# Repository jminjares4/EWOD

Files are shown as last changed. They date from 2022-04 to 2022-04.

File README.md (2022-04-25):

# **EWOD** :zap:

## **Description**
This repository hold the hardware designed files for EWOD Senior project. The hardware was developed in KiCAD.

## **Table of Contents**
* [3D](https://github.com/jminjares4/EWOD/tree/main/3D)
  * EWOD step file
* [Hardware](https://github.com/jminjares4/EWOD/tree/main/Hardware)
  * [EWOD KiCad](https://github.com/jminjares4/EWOD/tree/main/Hardware/EWOD%20KiCad)
  * [jlcpcb](https://github.com/jminjares4/EWOD/tree/main/Hardware/jlcpcb)
  * [Readme](https://github.com/jminjares4/EWOD/tree/main/Hardware/README.md)
* [Images](https://github.com/jminjares4/EWOD/tree/main/images)
  * EWOD schematic and printed circuit board (PCB)   
* [Readme](https://github.com/jminjares4/EWOD)

## **Requirements**
- [x] Surface mount SPDT Relays
  - [x] Onboard status LEDs 
- [x] Screw terminals
  - [x] AC Power
  - [x] Step-down transformer 
- [x] SPST Power switch
- [x] External UART to flash ESP32 
- [x] Testpoint
  - [x] 3.3V
  - [x] 5V
  - [x] 16V
  - [x] 164V  

## **EWOD PCB**
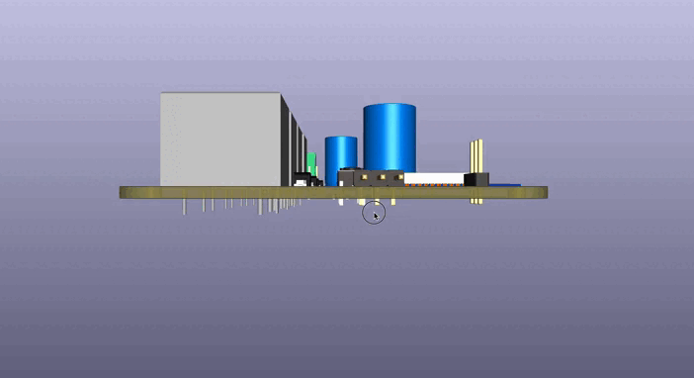
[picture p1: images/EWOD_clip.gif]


## **Development**
| **EWOD** | **Hardware/Software**|
| :--- | :--- |
|**Microcontroller**| |
|**Documentation**| |
| **Electronic Design Automation** ||

## **License**


## **Acknowledgements**
* ECE Department (UTEP)

## **Author**
* [**Jesus Minjares**](https://github.com/jminjares4)<br>
  * **Master of Science in Computer Engineering**<br>
 


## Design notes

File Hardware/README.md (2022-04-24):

# **EWOD Hardware** :zap:
This directory hold the hardware files for EWOD which was developed in KiCad.

## **Table of Contents**
* **EWOD KiCad**
  * EWOD hardware development was done in KiCad
* **jlcpcb**
  * JLCPCB files for assembly and gerber files

## **Schematic**
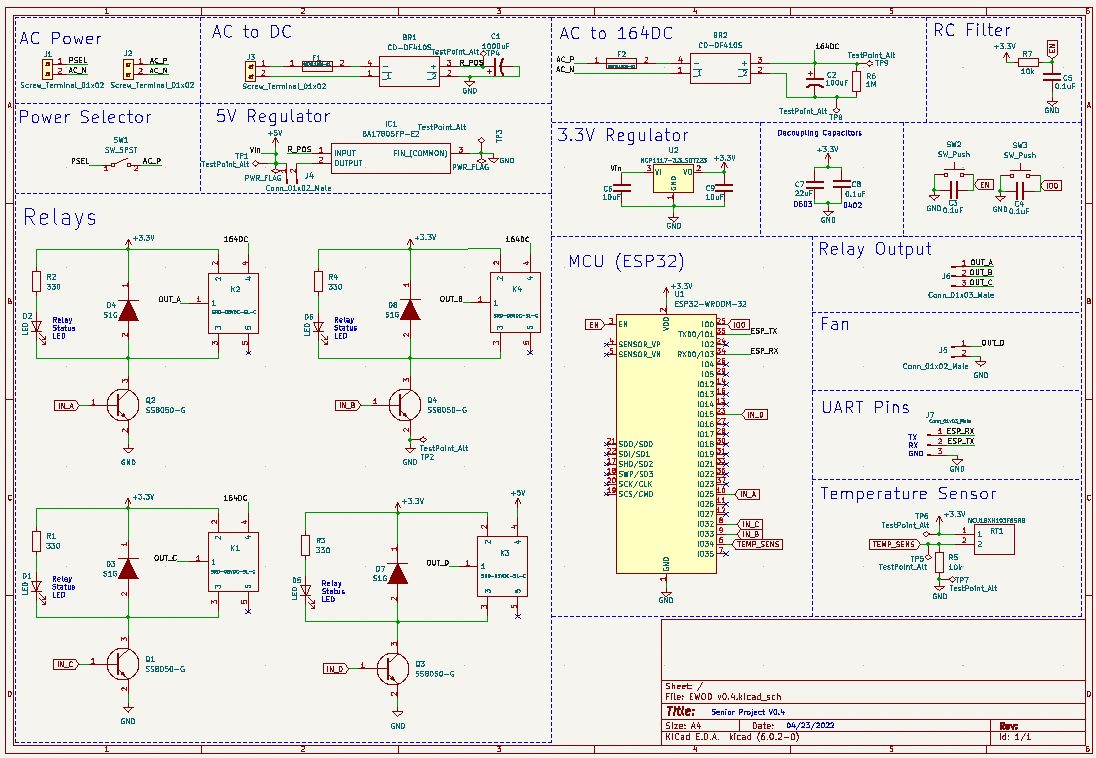
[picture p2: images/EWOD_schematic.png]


## **Top Layer**
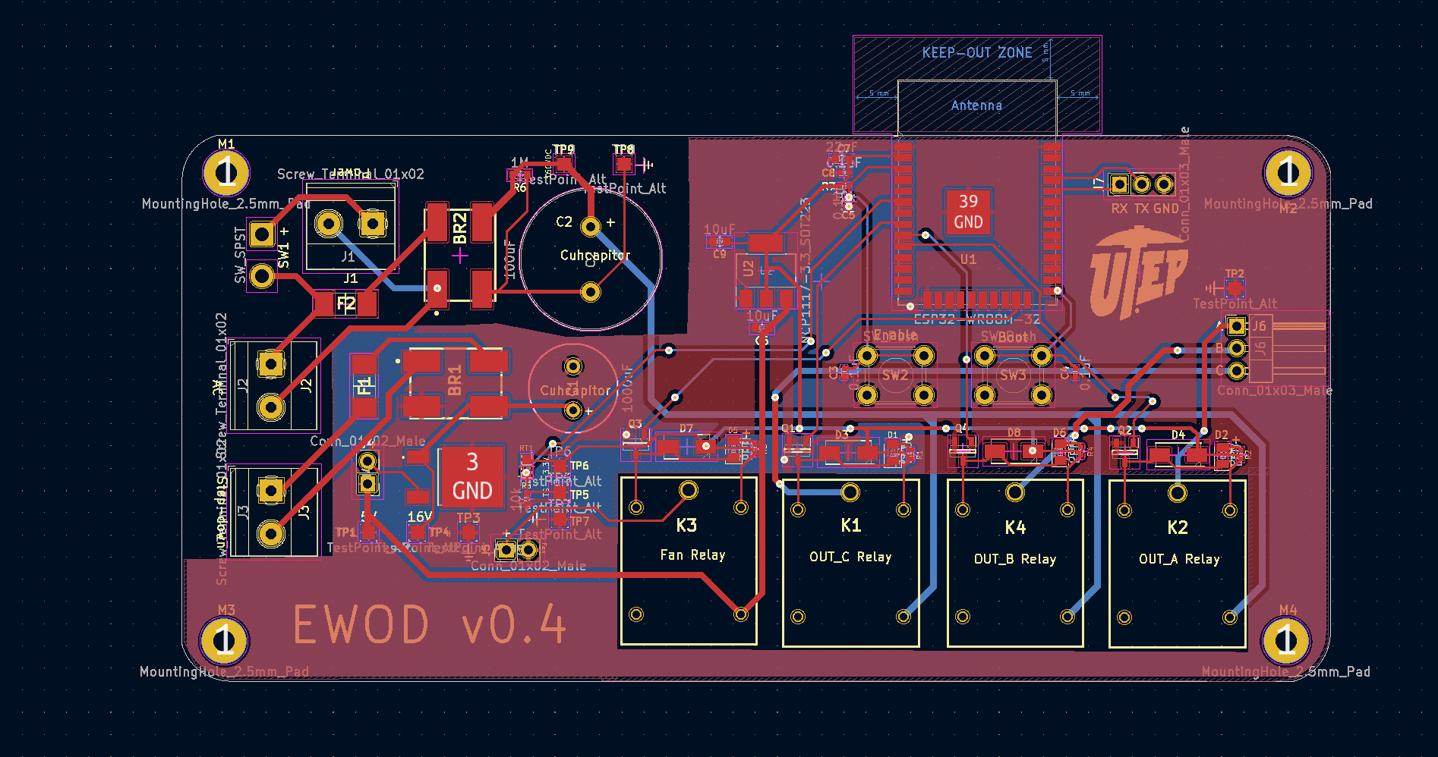
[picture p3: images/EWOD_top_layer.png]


## **Bottom Layer**
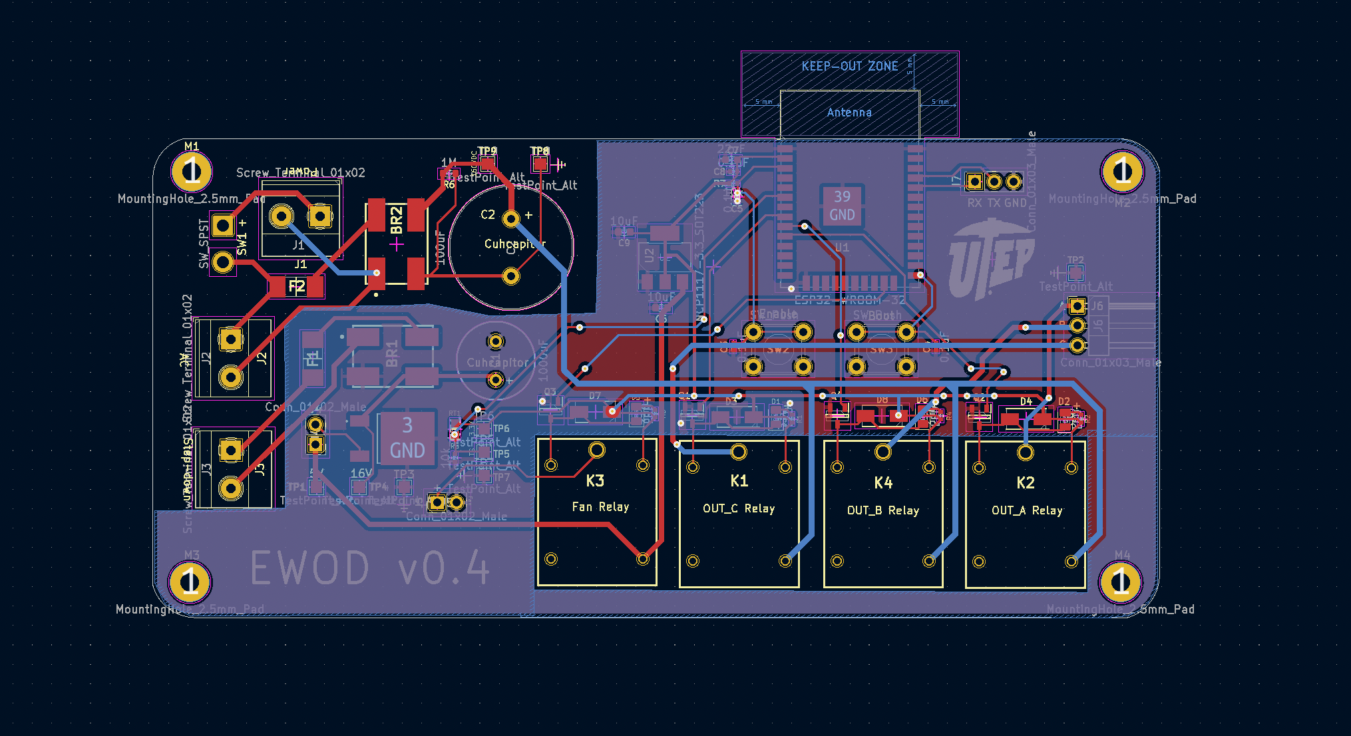
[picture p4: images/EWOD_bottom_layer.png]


## **Printed Circuit Board**
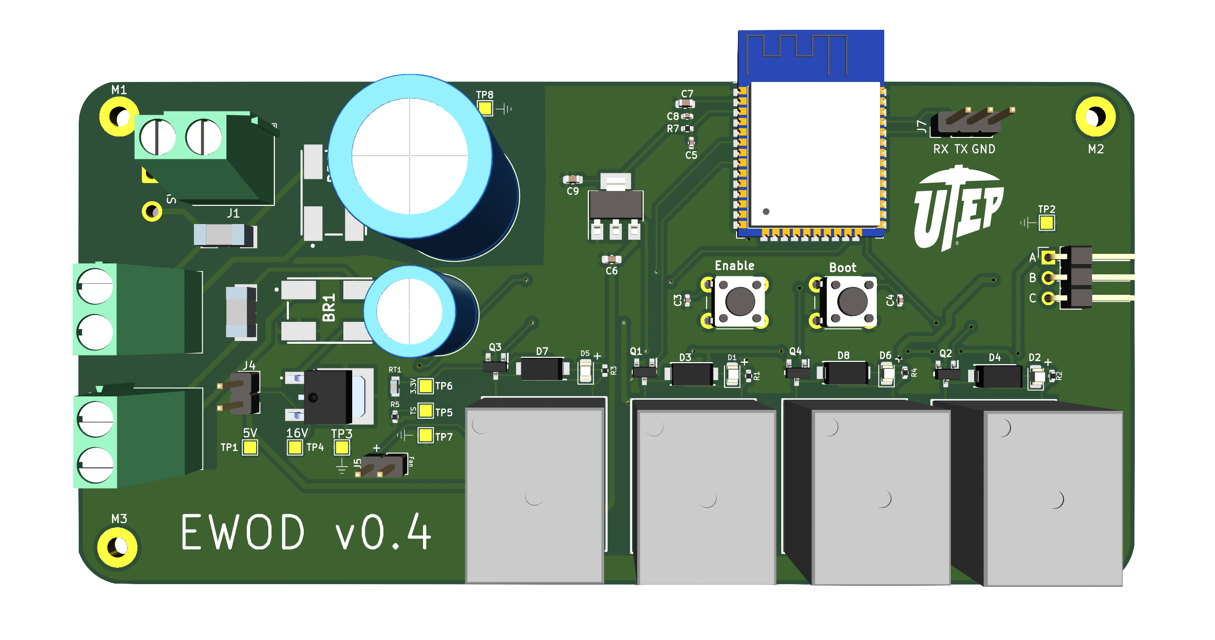
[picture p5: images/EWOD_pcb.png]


## **Author**
* [**Jesus Minjares**](https://github.com/jminjares4)<br>
  * **Master of Science in Computer Engineering**<br>
 


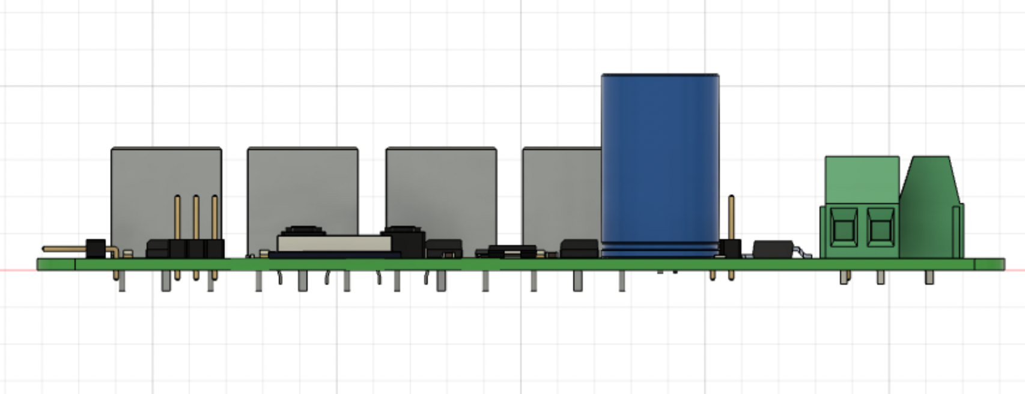
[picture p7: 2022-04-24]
images/EWOD_3D_side.png

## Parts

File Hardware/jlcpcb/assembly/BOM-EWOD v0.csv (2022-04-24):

Comment | Designator | Footprint | LCSC
0679L1000-01 | F1 | FUSC6125X279N
TestPoint_Alt | TP4 | TestPoint_Pad_1.5x1.5mm
ESP32-WROOM-32 | U1 | ESP32-WROOM-32
Screw_Terminal_01x02 | J2 | TerminalBlock_Phoenix_MKDS-1,5-2_1x02_P5.00mm_Horizontal
0.1uF | C3 | C_0402_1005Metric
SW_SPST | SW1 | SolderWire-0.75sqmm_1x02_P4.8mm_D1.25mm_OD2.3mm
330 | R1 | R_0402_1005Metric
S1G | D4 | DIOM5227X250N
SRD-05VDC-SL-C | K1 | SRD
SW_Push | SW2 | SW_PUSH_6mm
Screw_Terminal_01x02 | J1 | TerminalBlock_Phoenix_MKDS-1,5-2_1x02_P5.00mm_Horizontal
TestPoint_Alt | TP9 | TestPoint_Pad_1.5x1.5mm
SRD-05VDC-SL-C | K4 | SRD
330 | R3 | R_0402_1005Metric
Conn_01x03_Male | J7 | PinHeader_1x03_P2.54mm_Vertical
100uF | C2 | C_Radial_D16.0mm_H25.0mm_P7.50mm
NCU18XH103F6SRB | RT1 | THRMC1608X95N
Screw_Terminal_01x02 | J3 | TerminalBlock_Phoenix_MKDS-1,5-2_1x02_P5.00mm_Horizontal
TestPoint_Alt | TP3 | TestPoint_Pad_1.5x1.5mm
LED | D2 | LED_0805_2012Metric
1M | R6 | R_0603_1608Metric
S1G | D3 | DIOM5227X250N
TestPoint_Alt | TP2 | TestPoint_Pad_1.5x1.5mm
330 | R2 | R_0402_1005Metric
CD-DF410S | BR2 | CD-DF410S
SS8050-G | Q3 | SOT95P240X115-3N
TestPoint_Alt | TP8 | TestPoint_Pad_1.5x1.5mm
TestPoint_Alt | TP1 | TestPoint_Pad_1.5x1.5mm
LED | D6 | LED_0805_2012Metric
NCP1117-3.3_SOT223 | U2 | SOT-223-3_TabPin2
SRD-05VDC-SL-C | K3 | SRD
10k | R5 | R_0402_1005Metric
SS8050-G | Q2 | SOT95P240X115-3N
SRD-05VDC-SL-C | K2 | SRD
10uF | C6 | C_0603_1608Metric
Conn_01x02_Male | J4 | PinHeader_1x02_P2.54mm_Vertical
TestPoint_Alt | TP6 | TestPoint_Pad_1.5x1.5mm
0.1uF | C5 | C_0402_1005Metric
S1G | D7 | DIOM5227X250N
CD-DF410S | BR1 | CD-DF410S
BA17805FP-E2 | IC1 | ROHM_TO-252-3
10uF | C9 | C_0603_1608Metric
LED | D1 | LED_0805_2012Metric
22uF | C7 | C_0603_1608Metric
10k | R7 | R_0402_1005Metric
Conn_01x02_Male | J5 | PinHeader_1x02_P2.54mm_Vertical
0.1uF | C4 | C_0402_1005Metric
0.1uF | C8 | C_0402_1005Metric
1000uF | C1 | C_Radial_D10.0mm_H16.0mm_P5.00mm
330 | R4 | R_0402_1005Metric
TestPoint_Alt | TP5 | TestPoint_Pad_1.5x1.5mm
Conn_01x03_Male | J6 | PinHeader_1x03_P2.54mm_Horizontal
TestPoint_Alt | TP7 | TestPoint_Pad_1.5x1.5mm
SS8050-G | Q4 | SOT95P240X115-3N
SS8050-G | Q1 | SOT95P240X115-3N
S1G | D8 | DIOM5227X250N
LED | D5 | LED_0805_2012Metric
SW_Push | SW3 | SW_PUSH_6mm
0679L1000-01 | F2 | FUSC6125X279N

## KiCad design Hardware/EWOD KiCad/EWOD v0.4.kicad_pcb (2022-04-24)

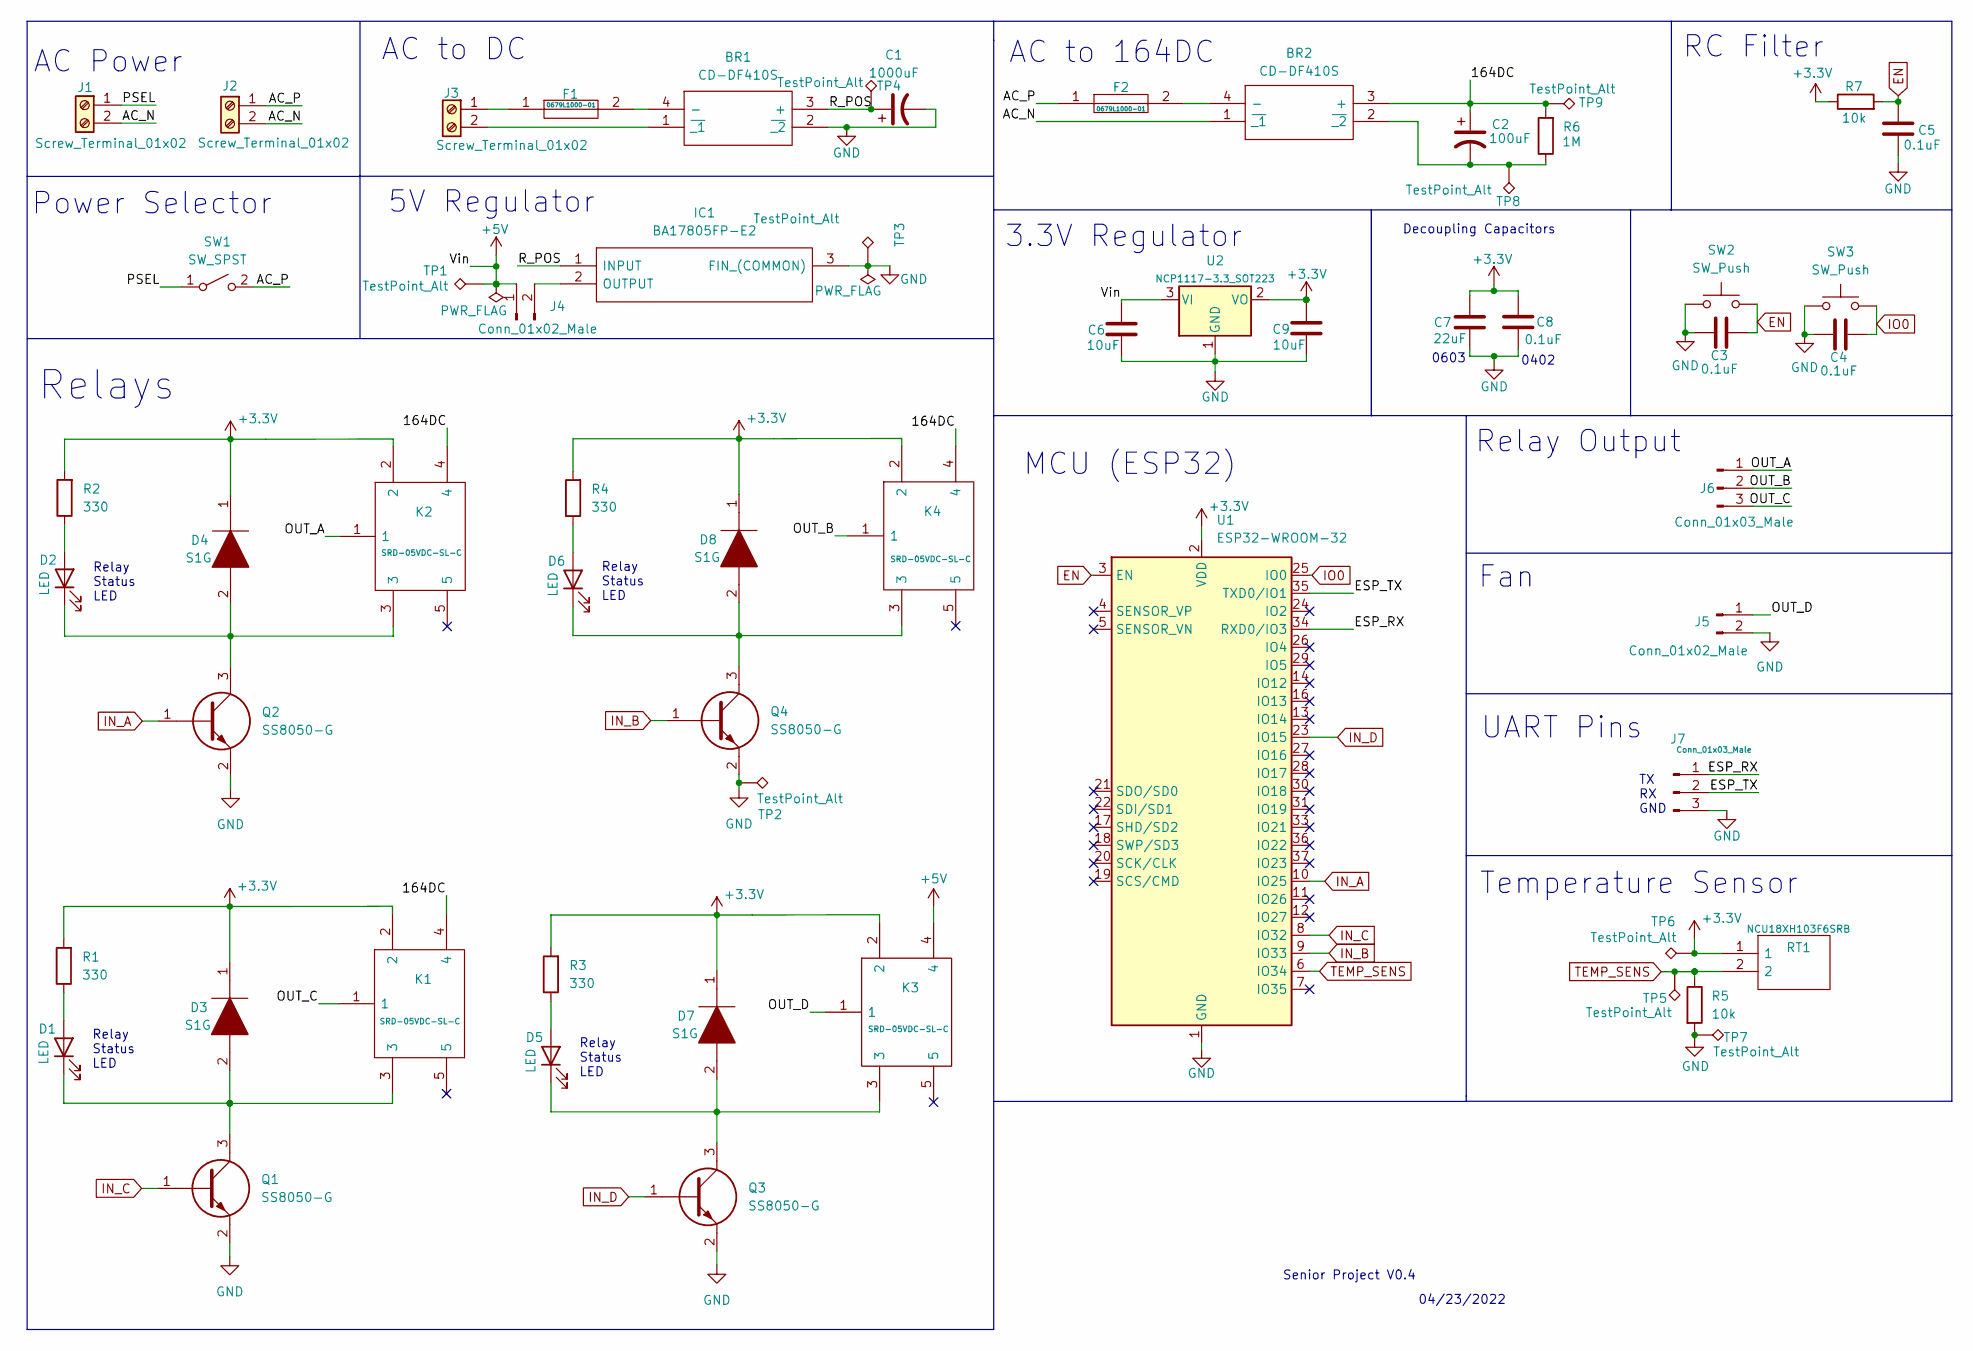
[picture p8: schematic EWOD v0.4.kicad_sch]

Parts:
BR1, BR2: CD-DF410S; Manufacturer_Part_Number CD-DF410S; Mouser Part Number 652-CD-DF410S
C1: 1000uF; C_Radial_D10.0mm_H16.0mm_P5.00mm
C2: 100uF; C_Radial_D16.0mm_H25.0mm_P7.50mm
C3, C4, C5, C8: 0.1uF; C_0402_1005Metric
C6, C9: 10uF; C_0603_1608Metric
C7: 22uF; C_0603_1608Metric
D1, D2, D5, D6: LED; LED_0805_2012Metric
D3, D4, D7, D8: S1G; DIOM5227X250N; Manufacturer_Part_Number S1G; Mouser Part Number 512-S1G
F1, F2: 0679L1000-01; FUSC6125X279N; Manufacturer_Part_Number 0679L1000-01
IC1: BA17805FP-E2; ROHM_TO-252-3; Manufacturer_Part_Number BA17805FP-E2; Mouser Part Number 755-BA17805FP-E2
J1, J2, J3: Screw_Terminal_01x02; TerminalBlock_Phoenix_MKDS-1,5-2_1x02_P5.00mm_Horizontal
J4, J5: Conn_01x02_Male; PinHeader_1x02_P2.54mm_Vertical
J6: Conn_01x03_Male; PinHeader_1x03_P2.54mm_Horizontal
J7: Conn_01x03_Male; PinHeader_1x03_P2.54mm_Vertical
K1, K2, K3, K4: SRD-05VDC-SL-C; SRD; Manufacturer_Part_Number SRD-05VDC-SL-C
Q1, Q2, Q3, Q4: SS8050-G; SOT95P240X115-3N; Manufacturer_Part_Number SS8050-G; Mouser Part Number 750-SS8050-G
R1, R2, R3, R4: 330; R_0402_1005Metric
R5, R7: 10k; R_0402_1005Metric
R6: 1M; R_0603_1608Metric
RT1: NCU18XH103F6SRB; THRMC1608X95N; Manufacturer_Part_Number NCU18XH103F6SRB; Mouser Part Number 81-NCU18XH103F6SRB
SW1: SW_SPST; SolderWire-0.75sqmm_1x02_P4.8mm_D1.25mm_OD2.3mm
SW2, SW3: SW_Push; SW_PUSH_6mm
TP1, TP2, TP3, TP4, TP5, TP6, TP7, TP8, TP9: TestPoint_Alt; TestPoint_Pad_1.5x1.5mm
U1: ESP32-WROOM-32
U2: NCP1117-3.3_SOT223; SOT-223-3_TabPin2

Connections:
+3V3: C7.1, C8.1, C9.1, D3.1, D4.1, D7.1, D8.1, K1.2, K2.2, K3.2, K4.2, R1.2, R2.2, R3.2, R4.2, R7.1, RT1.1, TP6.1, U1.2 (VDD), U2.2 (VO)
+5V: C6.1, J4.1, K3.4, TP1.1, U2.3 (VI)
/164DC: BR2.3 (+), C2.1, K1.4, K2.4, K4.4, R6.2, TP9.1
/AC_N: BR2.1 (~_1), J1.2, J2.2
/AC_P: F2.1, J2.1, SW1.2 (B)
/ESP_RX: J7.1, U1.34 (RXD0/IO3)
/ESP_TX: J7.2, U1.35 (TXD0/IO1)
/OUT_A: J6.1, K2.1
/OUT_B: J6.2, K4.1
/OUT_C: J6.3, K1.1
/OUT_D: J5.1, K3.1
/PSEL: J1.1, SW1.1 (A)
/R_POS: BR1.3 (+), C1.1, IC1.1 (INPUT), TP4.1
EN: C3.2, C5.1, R7.2, SW2.2, U1.3 (EN)
GND: BR1.2 (~_2), C1.2, C3.1, C4.1, C5.2, C6.2, C7.2, C8.2, C9.2, IC1.3 (FIN_(COMMON)), J5.2, J7.3, Q1.2, Q2.2, Q3.2, Q4.2, R5.2, SW2.1, SW3.1, TP2.1, TP3.1, TP7.1, U1.1 (GND), U1.15 (GND), U1.38 (GND), U1.39 (GND), U2.1 (GND)
IN_A: Q2.1, U1.10 (IO25)
IN_B: Q4.1, U1.9 (IO33)
IN_C: Q1.1, U1.8 (IO32)
IN_D: Q3.1, U1.23 (IO15)
IO0: C4.2, SW3.2, U1.25 (IO0)
unnamed: BR1.1 (~_1), J3.2
unnamed: BR1.4 (-), F1.2
unnamed: BR2.2 (~_2), C2.2, R6.1, TP8.1
unnamed: BR2.4 (-), F2.2
unnamed: D1.1 (K), D3.2, K1.3, Q1.3
unnamed: D1.2 (A), R1.1
unnamed: D2.1 (K), D4.2, K2.3, Q2.3
unnamed: D2.2 (A), R2.1
unnamed: D5.1 (K), D7.2, K3.3, Q3.3
unnamed: D5.2 (A), R3.1
unnamed: D6.1 (K), D8.2, K4.3, Q4.3
unnamed: D6.2 (A), R4.1
unnamed: F1.1, J3.1
unnamed: IC1.2 (OUTPUT), J4.2
TEMP_SENS: R5.1, RT1.2, TP5.1, U1.6 (IO34)

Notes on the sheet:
Power Selector
AC Power
Fan
Relay Status LED
Relays
04/23/2022
Decoupling Capacitors
0603
RC Filter
Senior Project V0.4
AC to DC
Temperature Sensor
3.3V Regulator
0402
Relay Output
TX RX GND
5V Regulator
UART Pins
MCU (ESP32)
AC to 164DC

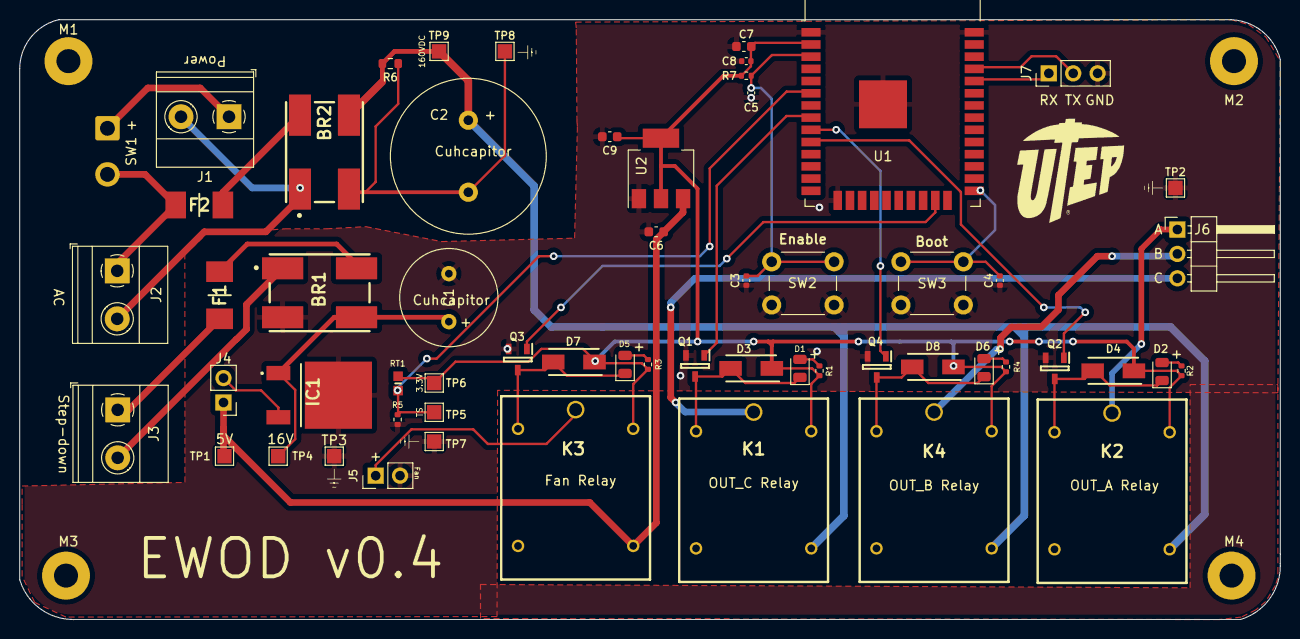
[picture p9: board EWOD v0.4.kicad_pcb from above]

Board: 2 copper layers, 131.3 x 62.5 mm, 63 parts (0 on the bottom side), 35 nets.

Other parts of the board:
M1, M2, M3, M4: MountingHole_2.5mm_Pad

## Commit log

2022-04-24 Added EWOD v0.4 hardware development
    [BOM-EWOD v0.csv, EWOD v0.4.kicad_pcb, EWOD v0.4.kicad_sch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]
2022-04-24 Moved everything to subdirectory
    [BOM-EWOD v0.csv, EWOD v0.4.kicad_pcb, EWOD v0.4.kicad_sch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]
2022-04-24 Updated hardware repo
    [BOM-EWOD v0.csv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]

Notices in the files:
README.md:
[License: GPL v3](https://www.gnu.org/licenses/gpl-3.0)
